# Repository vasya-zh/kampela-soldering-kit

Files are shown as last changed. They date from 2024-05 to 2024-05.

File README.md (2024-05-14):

# kampela-soldering-kit

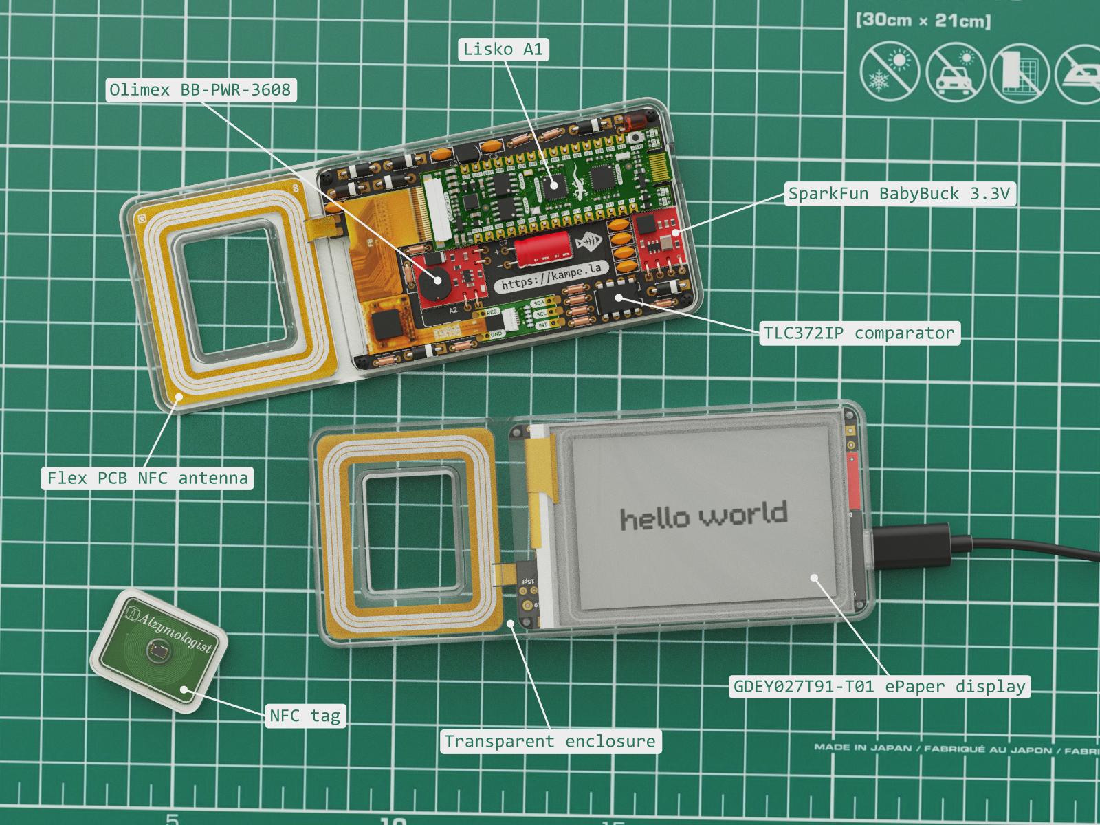
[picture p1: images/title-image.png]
kampela-soldering-kit title image


## Overview

Do-it-yourself kit to make your own, fully-functional Kampela signer

## Features
- Easy to solder and self-assembly transaction signer kit
- NFC-powered batteryless operation
- secure vault implemented in EFM32PG23 MCU
- 2.7" ePaper display with touchscreen
- you can fill the assembled kit with transparent UV-cured glue after assembly and tests to make it unchangeable

## Why did we create this?

We want to make kampela design as transparent, verifiable and open-source as possible, that's simple.

## Components

Kampela solder kit consists of several off-the-shelf modules, simple electronic components and 3d printed parts:

**Modules:**
- 1pc - [Lisko A1](https://github.com/vasya-zh/Lisko) EFM32 devboard
- 1pc - [SparkFun BabyBuck 3.3V](https://www.sparkfun.com/products/18357) - step-down converter module 
- 1pc - [Olimex BB-PWR-3608](https://www.olimex.com/Products/Breadboarding/BB-PWR-3608/open-source-hardware) - step-up converter module 12V/24V
- 1pc - [Touch-6pin-adapter](https://github.com/vasya-zh/kampela-soldering-kit/tree/v2/kicad/touch-6pin-adapter) - 6-pin 0.5mm pitch FPC cable adapter for i2c touch screens
- 1pc - [NFC tag](https://github.com/vasya-zh/kampela-soldering-kit/tree/v2/kicad/tag) PCB with M24SR02 NFC EEPROM chip onboard

**PCBs:**
- 1pc - [Base-board](kicad/base-board/) - main Kampela soldering kit PCB
- 1pc - [flex nfc antenna](https://github.com/vasya-zh/kampela-soldering-kit/tree/v2/kicad/flex-coil8/production) PCB

**3d printed parts:**
- 1pc - [Solder kit enclosure](3d-models/solder-kit-enclosure.stl), 3d printed with transparent SLA resin
- 1pc - [NFC tag enclosure](3d-models/nfc-tag-enclosure.stl), 3d printed with transparent SLA resin

**Electronic components:**
- 1pc - [GDEY027T91-T01](https://www.good-display.com/product/259.html) ePaper display
- 1pc - [TLC372IP](https://www.ti.com/lit/ds/symlink/tlc372.pdf?ts=1715700121988&ref_url=https%253A%252F%252Fwww.google.com%252F) - comparator in DIP8 package
- 1pc - [L78L24](https://www.st.com/resource/en/datasheet/l78l.pdf) - 24V linear voltage regulator in TO-92 package 
- 6pcs - [1N5819](https://www.vishay.com/docs/88525/1n5817.pdf) schottky diode 40V 1A
- 1pc - [1N4743A](https://www.nexperia.com/products/diodes/zener-diodes/1N4743A.html) 13V 1W Zener diode
- 1pc - [3mm red LED](https://www.mouser.fi/ProductDetail/Vishay-Semiconductors/TLDR4900?qs=Lv5%252BaqTFJEN9M2YxsERGfA%3D%3D) for NFC field presence indication 

**Capacitors:**
- 1pc - [15pF 50V](https://www.lcsc.com/product-detail/Multilayer-Ceramic-Capacitors-MLCC-Leaded_TORCH-CC4-0805-CG-50V-15pF-J_C123158.html) ceramic capacitor
- 2pcs - [100pF 50V](https://www.lcsc.com/product-detail/Multilayer-Ceramic-Capacitors-MLCC-Leaded_Murata-Electronics-RCE5C2A101J0DBH03A_C1622101.html) ceramic capacitor
- 2pcs - [0.1uF 50V](https://www.lcsc.com/product-detail/Multilayer-Ceramic-Capacitors-MLCC-Leaded_KNSCHA-178MU0006_C5632430.html) ceramic capacitor
- 2pcs - [1uF 50V](https://www.lcsc.com/product-detail/Multilayer-Ceramic-Capacitors-MLCC-Leaded_KNSCHA-178MU0010_C5632434.html) ceramic capacitor
- 1pc - [220uF 25V](https://www.lcsc.com/product-detail/Aluminum-Electrolytic-Capacitors-Leaded_CX-Dongguan-Chengxing-Elec-KM227M025E11RR0VH2FP0_C12450.html) aluminium capacitor d6.3mm\*11mm

**Resistors:**
- 4pcs - [10k 0.125w](https://www.lcsc.com/product-detail/Through-Hole-Resistors_VO-MF1-8W-10K-1-ST26_C2903381.html) resistor
- 6pcs - [47k 0.125w](https://www.lcsc.com/product-detail/Through-Hole-Resistors_Futaba-Elec-RNU18F4702A520NH_C274421.html) resistor
- 1pc - [300k 0.125w](https://www.lcsc.com/product-detail/Through-Hole-Resistors_TyoHM-RN-1-8W-300K-F-T-B-A1_C433482.html) resistor

Complete CSV BOM can be found [here](docs/kampela-soldering-kit-BOM.csv)

## Assembly instructions

Assembly instructions can be found here: [/docs/assembly-manual.md](docs/assembly-manual.md)

> [!Note] 
> Don't fill your assembly with transparent UV adhesive before you fully test it and flash it with the right firmware.  

## Flashing and testing

Flashing and testing instructions can be found here: [/docs/flashing-n-testing.md](docs/flashing-n-testing.md)

## Using your Kampela Solder Kit

You can use your solder kit as a transaction signer with the real [Kampela firmware](https://github.com/Kalapaja/kampela-firmware)

To do that you need to flash it with the latest [binary firmware released](https://github.com/Kalapaja/kampela-firmware/tags) or build it from the [source code](https://github.com/Kalapaja/kampela-firmware)

Or you can make your customized version of the firmware and hardware.

## How to produce your own Kampela Solder Kit

You can get the kit in [kampe.la](https://kampe.la) shop

Or make your kit. To do that you need:
- order PCBs from your favourite PCB manufacturer. Gerber files can be found here: [base-board](https://github.com/vasya-zh/kampela-soldering-kit/tree/v2/kicad/base-board/production), [flex-antenna](https://github.com/vasya-zh/kampela-soldering-kit/tree/v2/kicad/flex-coil8/production)
- order modules and electronic components, see the [full BOM](docs/kampela-soldering-kit-BOM.csv)
- order or print enclosures with transparent SLA resin. STL and STEP files can be found [here](3d-models/)
- if you want you can also make your version of [Lisko A1](https://github.com/vasya-zh/Lisko) board and [FPC adapter](https://github.com/vasya-zh/kampela-soldering-kit/tree/v2/kicad/touch-6pin-adapter) board. Overwise contact [kampela team](https://kampe.la)

## About this design

Schematic PDF diagrams can be found [here](docs/)

KiCad projects can be found [here](kicad/)

This kit was made using only open-source tools:
- [KiCad](https://www.kicad.org/) - for schematics and PCBs
- [FreeCad](https://www.freecad.org/) - for enclosure design
- [Blender](https://www.blender.org/) - for renders and images
- [InkScape](https://inkscape.org/) - for instructions diagrams

## TODO
- ! Change ePaper and touch screen RESET signal polarity in test and release firmware! 

## Contributors

- [Vasilii Zhuravskii](https://github.com/vasya-zh) - solder kit v2 design, schematics, boards design, DFM, docs, tests

- [Yuri Ilin](https://www.youtube.com/@katsuk) - solder kit v1 design, schematics, flasher firmware, EFM32 test firmware in C with E-INK and other features

This project was made at [Alzymologist Oy](https://github.com/alzymologist) as a part of [Kampela](https://kampe.la) project.

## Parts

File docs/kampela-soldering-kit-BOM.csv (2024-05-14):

Reference | Part Number | URL | Qty | LCSC Part #
A1 | Lisko A1 | https://github.com/vasya-zh/Lisko | 1 | -
A2 | BB-PWR-3608 | https://www.olimex.com/Products/Breadboarding/BB-PWR-3608/open-source-hardware | 1 | -
A3 | BabyBuck 3.3V | https://www.sparkfun.com/products/18357 | 1 | -
A4 | Touch-6pin-adapter | https://github.com/vasya-zh/kampela-soldering-kit/tree/v2/kicad/touch-6pin-adapter | 1 | -
 | NFC tag | https://github.com/vasya-zh/kampela-soldering-kit/tree/v2/kicad/tag | 1 | -
 | Base-board PCB | https://github.com/vasya-zh/kampela-soldering-kit/tree/v2/kicad/base-board | 1 | -
 | Flex NFC antenna PCB | https://github.com/vasya-zh/kampela-soldering-kit/tree/v2/kicad/flex-coil8 | 1 | -
 | Solder kit enclosure | https://github.com/vasya-zh/kampela-soldering-kit/blob/v2/3d-models/solder-kit-enclosure.stl | 1 | -
 | NFC tag enclosure | https://github.com/vasya-zh/kampela-soldering-kit/blob/v2/3d-models/nfc-tag-enclosure.stl | 1 | -
 | GDEY027T91-T01 | https://www.good-display.com/product/259.html | 1 | -
 | M2x3 self-tapping screws |  | 4 | -
 | 1mm thick 10mm double side tape, 2x50mm pieces |  | 2 | -
 | UV transparent adhesive 30ml and UV curing LED |  | 1 | -
C1 | 15pF 100V | https://www.lcsc.com/product-detail/Multilayer-Ceramic-Capacitors-MLCC-Leaded_TORCH-CC4-0805-CG-50V-15pF-J_C123158.html | 1 | C123158
C2,C3 | 1uF 50V | https://www.lcsc.com/product-detail/Multilayer-Ceramic-Capacitors-MLCC-Leaded_KNSCHA-178MU0010_C5632434.html | 2 | C5632434
C4,C5 | 100pF 100V | https://www.lcsc.com/product-detail/Multilayer-Ceramic-Capacitors-MLCC-Leaded_Murata-Electronics-RCE5C2A101J0DBH03A_C1622101.html | 2 | C1622101
C6,C8 | 0,1uF 50V | https://www.lcsc.com/product-detail/Multilayer-Ceramic-Capacitors-MLCC-Leaded_KNSCHA-178MU0006_C5632430.html | 2 | C5632430
C7 | 220uF 25V | https://www.lcsc.com/product-detail/Aluminum-Electrolytic-Capacitors-Leaded_CX-Dongguan-Chengxing-Elec-KM227M025E11RR0VH2FP0_C12450.html | 1 | C12450
D1,D2,D3,D4,D5,D8 | 1N5819 | https://www.vishay.com/docs/88525/1n5817.pdf | 6 | C2474
D6 | XL-234SURD-L | https://www.lcsc.com/product-detail/Light-Emitting-Diodes-LED_XINGLIGHT-XL-234SURD-L_C5440555.html | 1 | C5440555
D7 | 1N4743A | https://www.nexperia.com/products/diodes/zener-diodes/1N4743A.html | 1 | C2546
R1,R7,R8,R9 | 10k | https://www.lcsc.com/product-detail/Through-Hole-Resistors_VO-MF1-8W-10K-1-ST26_C2903381.html | 4 | C2903381
R2,R3,R4,R5,R6,R11 | 47k | https://www.lcsc.com/product-detail/Through-Hole-Resistors_Futaba-Elec-RNU18F4702A520NH_C274421.html | 6 | C274421
R10 | 300k | https://www.lcsc.com/product-detail/Through-Hole-Resistors_TyoHM-RN-1-8W-300K-F-T-B-A1_C433482.html | 1 | C433482
U1 | L7824 | http://www.st.com/content/ccc/resource/technical/document/datasheet/41/4f/b3/b0/12/d4/47/88/CD00000444.pdf/files/CD00000444.pdf/jcr:content/translations/en.CD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 | 1 | C903167
U2 | TLC372IP | https://www.ti.com/lit/ds/symlink/tlc372.pdf?ts=1714659513681 | 1 | C2862094

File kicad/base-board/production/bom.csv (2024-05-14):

Designator | Footprint | Quantity | Value | LCSC Part #
A1 | Lisko_A01-DIP-only | 1 | Lisko_A01 | -
A2 | BB-PWR-3608-in-board | 1 | BB-PWR-3608 | -
A3 | SparkFun_BabyBuck_3.3V-in-board | 1 | BabyBuck 3.3V | -
A4 | touch-6pin-adapter | 1 |  | -
C1 | C_Disc_D5.0mm_W2.5mm_P2.50mm | 1 | 15pF 100V | C123158
C2, C3 | C_Disc_D5.0mm_W2.5mm_P2.50mm | 2 | 1uF 50V | C5632434
C4, C5 | C_Disc_D5.0mm_W2.5mm_P2.50mm | 2 | 100pF 100V | C1622101
C6, C8 | C_Disc_D5.0mm_W2.5mm_P2.50mm | 2 | 0,1uF 50V | C5632430
C7 | CAP_RADIAL_6.3_2.5_11_HOR-DIP | 1 | 220uF 25V | C12450
D1, D2, D3, D4, D5, D8 | D_DO-41_SOD81_P7.62mm_Horizontal | 6 | 1N5819 | C2474
D6 | LED_Rectangular_W3.0mm_H2.0mm | 1 | XL-234SURD-L | C5440555
D7 | D_DO-41_SOD81_P7.62mm_Horizontal | 1 | 13V Zener | C2546
J1, J2 | Pad_1.8x3 | 2 | E_ANT | -
R1, R7, R8, R9 | R_Axial_DIN0204_L3.6mm_D1.6mm_P5.08mm_Horizontal | 4 | 10k | C2903381
R10 | R_Axial_DIN0204_L3.6mm_D1.6mm_P5.08mm_Horizontal | 1 | 300k | C433482
R11, R2, R3, R4, R5, R6 | R_Axial_DIN0204_L3.6mm_D1.6mm_P5.08mm_Horizontal | 6 | 47k | C274421
U1 | TO-92_Inline | 1 | L7824 | C903167
U2 | DIP-8_W7.62mm | 1 | TLC372IP | C2862094

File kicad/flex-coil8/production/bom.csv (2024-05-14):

Designator | Footprint | Quantity | Value | LCSC Part #
_2, |  | 2

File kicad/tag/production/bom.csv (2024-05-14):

Designator | Footprint | Quantity | Value | LCSC Part #
U1 | DFN-8-1EP_3x2mm_P0.5mm_EP1.3x1.5mm | 1 | M24SR02-YMC6T/2

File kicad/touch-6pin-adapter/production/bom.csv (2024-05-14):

Designator | Footprint | Quantity | Value | LCSC Part #
C1 | 0402 | 1 | 0.1uF | C5142567
J1 | HRS_FH34SRJ-6S-0.5SH_50_ | 1 | Conn_01x06 | C5213748
J2, J3 | Connector_Castelled_3pin_2.54mm_withVIA | 2 | Conn_01x03
R1, R2, R3, R4 | 0402 | 4 | 10k | C2906885

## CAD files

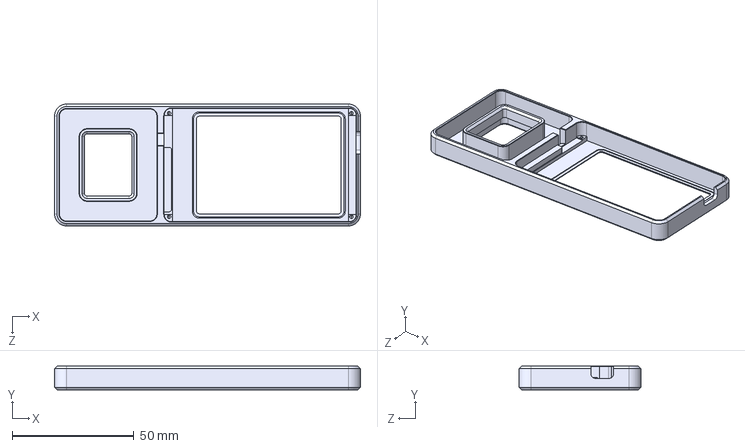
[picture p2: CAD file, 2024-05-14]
3d-models/solder-kit-enclosure.step
125.5 x 9.65 x 50.0 mm

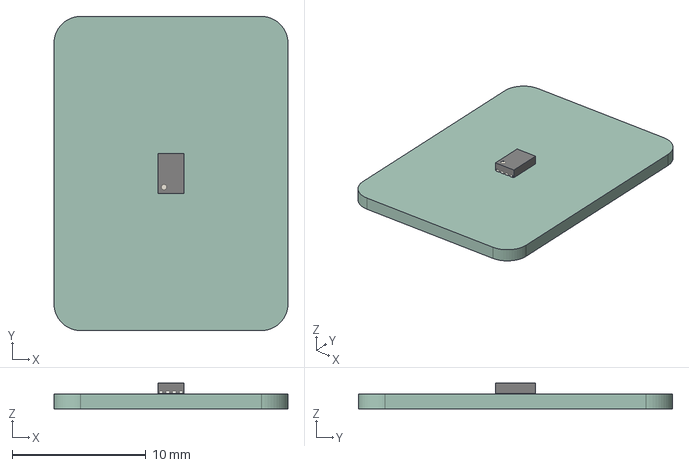
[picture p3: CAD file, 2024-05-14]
kicad/tag/Tag.kicad_G_pcb.step
17.5 x 23.5 x 1.91 mm
DFN-8-1EP_3x2mm_Pitch0.5mm
_autosave-Tag.kicad_G_pcb_PCB

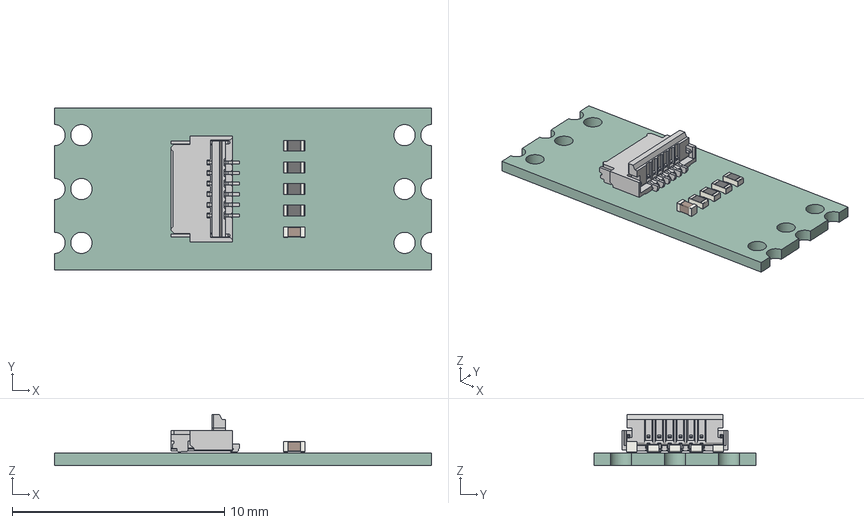
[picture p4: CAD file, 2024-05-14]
kicad/touch-6pin-adapter/touch-6pin-adapter.step
17.8 x 7.62 x 2.42 mm
FH34SRJ-6S_ACTUATOROPEN.PRT
C_0402_1005Metric
R_0402_1005Metric x 4
touch-6pin-adapter_PCB

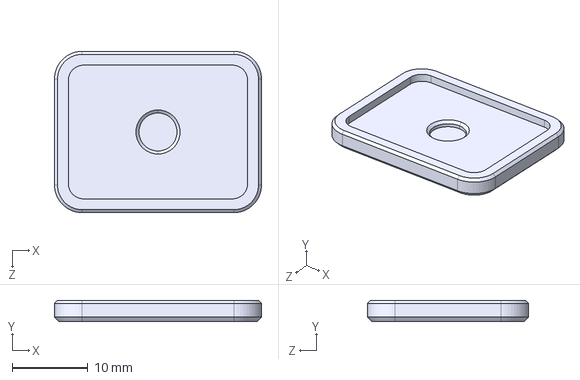
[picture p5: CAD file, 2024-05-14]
3d-models/nfc-tag-enclosure.step
27.2 x 2.80 x 21.2 mm

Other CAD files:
3d-models/nfc-tag-enclosure.stl
3d-models/solder-kit-enclosure.stl

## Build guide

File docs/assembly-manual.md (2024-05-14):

## Assembly Manual

> [!WARNING]
> Use the safety glass and fume extractor (simple 80mm PC vent suits too) to prevent cancer and eye diseases.<br>
> The sun is bright, the water is wet, a soldering iron is hot - be careful!

## Base-board assembly

> [!NOTE]
> A printable version of the base-board Assembly Manual can be found [here](images/base-board-assembly-manual.svg).<br>

0. Tools and materials:
- a soldering iron, 
- a soldering wire, 
- a lot of flux, 
- any cleaning solvent to clean flux after assembly (isopropanol etc) 
- and a good side cutters. 

1. Place and solder the FPC adapter board on the base-board with 6 soldering points:

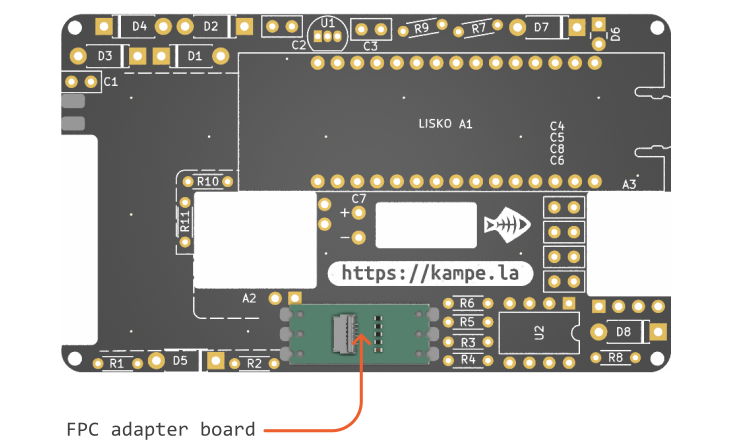
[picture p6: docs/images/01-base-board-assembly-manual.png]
Base-board assembly manual 01


2. Place and solder BB-PWR-3608 and BabyBuck 3.3V - red modules with short insulated or non-insulated copper wires:
	
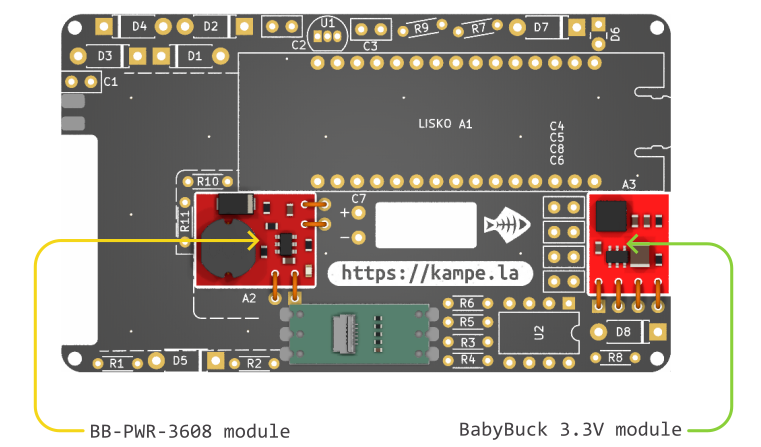
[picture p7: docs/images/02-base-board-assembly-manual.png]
Base-board assembly manual 02


3. Solder all the resistors 10k, 47k and 300k in their places

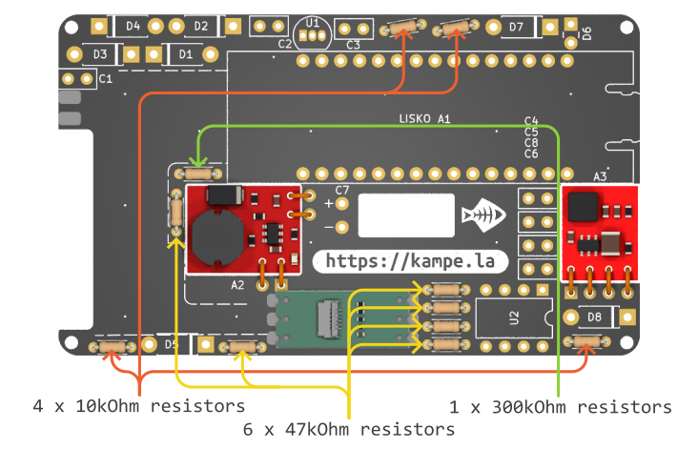
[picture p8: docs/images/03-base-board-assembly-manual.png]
Base-board assembly manual 03


4. Solder all the diodes including 13V Zener (1N4743A) and Schottky (1N5819) diodes

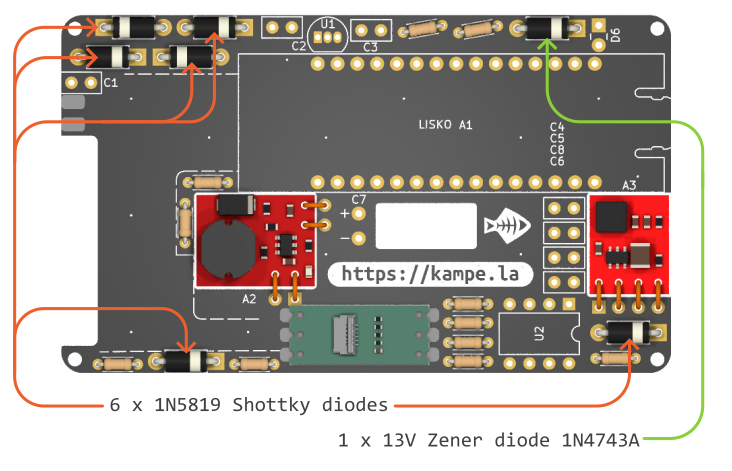
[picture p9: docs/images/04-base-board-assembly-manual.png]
Base-board assembly manual 04


5. Bend to 90 degrees (as short as possible) and solder 3mm red LED (or use the colour you want) to the base-board. Check the polarity on the bottom side of the board.

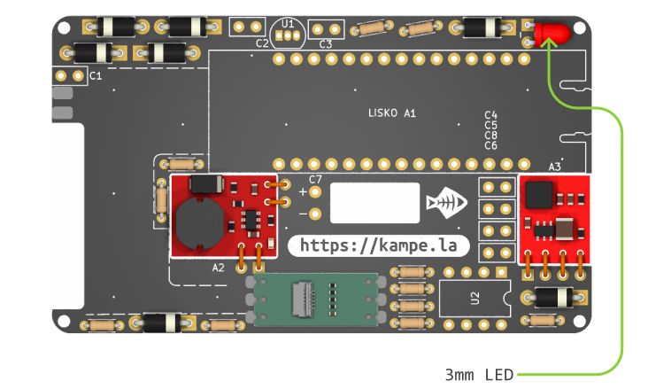
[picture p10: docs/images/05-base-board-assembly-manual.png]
Base-board assembly manual 05


6. Place and solder comparator IC (TLC372IP) and 24V linear regulator (L7824) as close to the board as possible (it will help you to make a flat assembled device).

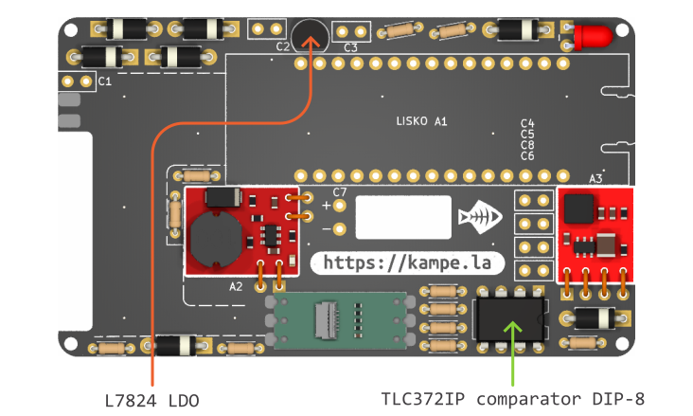
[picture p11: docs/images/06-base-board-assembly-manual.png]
Base-board assembly manual 06


7. Place and solder all capacitors - ceramic disc 15pF, 100pF, 100nF, 1uF (50V or higher voltage) and then aluminium 220uF (not less then 25V)

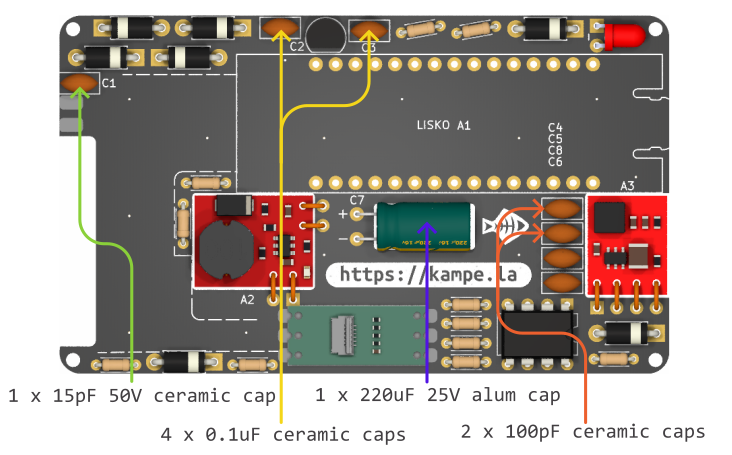
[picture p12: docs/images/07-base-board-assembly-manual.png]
Base-board assembly manual 07


8. Place and solder a Lisko A1 board to the base board using two 15-pin PLS 2.54-pitch male connectors.

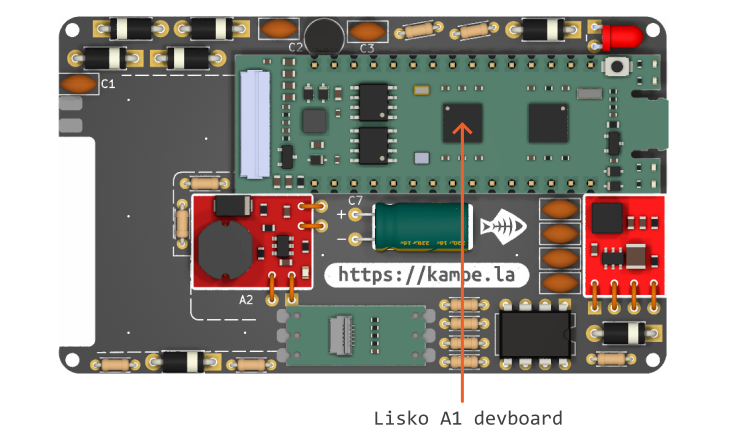
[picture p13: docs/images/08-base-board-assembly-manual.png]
Base-board assembly manual 08


9. Perfect! Now let's cut all the wires on the back side of the base board not higher than 0.5mm and clean the board from flux remains with isopropanol or other solvent

Base-board assembly manual 09

2. Solder the flex coil to the base board with 2 soldering points as shown below. Use water-cleanable or non-clean flux, we don't want to damage the flex coil sticker layer with solvent.

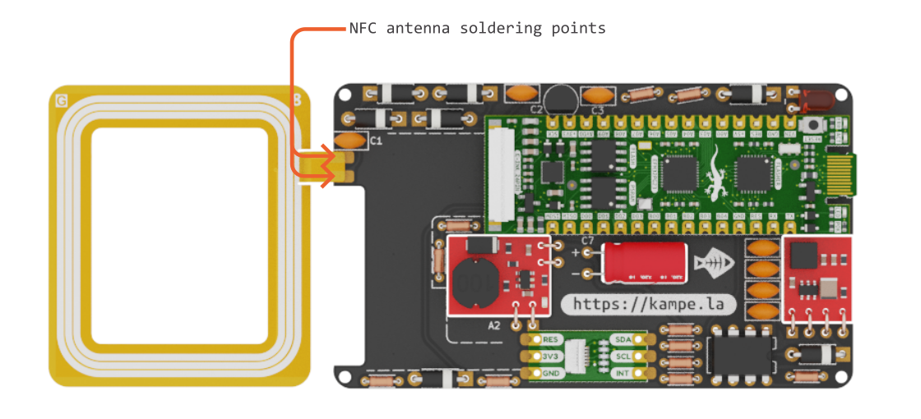
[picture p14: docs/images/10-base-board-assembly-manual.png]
Base-board assembly manual 10


3. Stick the flex dumper to the back side of the 2.7" E-INK display to protect it from PCB back wires and to push it in place 

3. Place the 2.7" E-INK display with a touch screen in the enclosure and push it to the upper edge of its place to align the visible area with the enclosure window. No need to fix it at this stage, it will be secured in place with a flex dumper after fixing the base-board PCB.

4. Install assembled base-board to the enclosure, getting E-INK and Touch screen flex cables outside. Fix it to the enclosure with four M1.6x3 self-tapping screws.

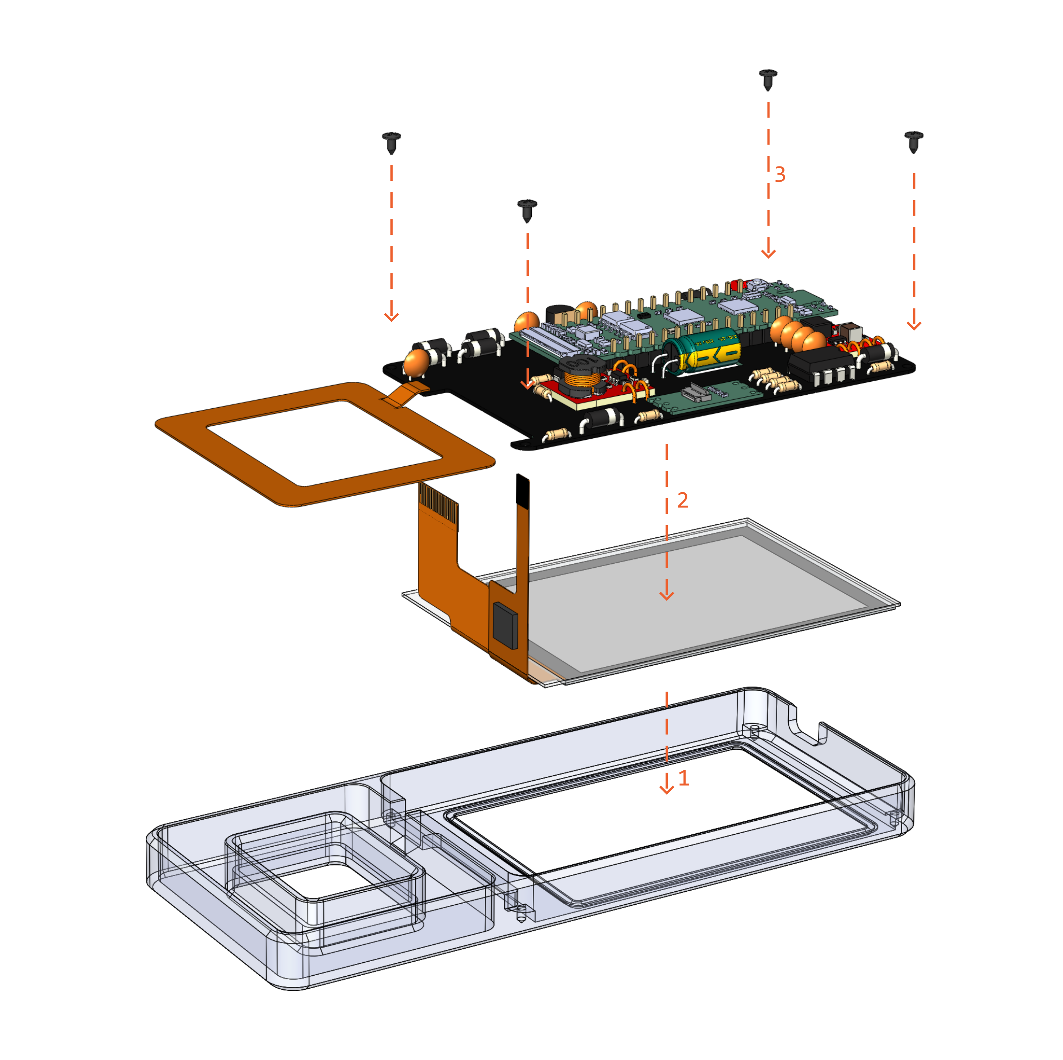
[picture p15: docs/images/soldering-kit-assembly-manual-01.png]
soldering kit assembly manual 01


5. Bend and insert the E-INK and Touch screen flex cables (orange ones) into their connectors - E-INK cable goes to Lisko 24-pin connector, touch screen cable goes to the fpc adapter 6-pin connector.

6. Unstick a protective layer on a flex coil and stick the coil in its place inside the enclosure.

7. Now let's assemble a dummy NFC tag used to initiate NFC communication with a phone. 

	You can use any NFC ISO/IEC 14443 Type A compatible tag you want - it will work with Siltti SDK.

	Or use [kit's NFC tag](https://github.com/Kalapaja/kampela-hardware/tree/main/tag) based on [M24SR02-YMC6T/2](https://www.st.com/en/nfc/m24sr02-y.html) 2-Kbit EEPROM NFC memory

	Install the tag PCB inside a 3d printed enclosure. You can stick it and fill it with transparent UV adhesive if you want but don't forget to test the tag before, for example with NFC Tools. It should be findable and possible to read its uID, that's enough for our task.

	You can use the tag on a key chain with a peace of strong wire. Without it Kampela won't work.

8. Install a companion tag to Kampela enclosure.

7. You've done it! Let's get some Club-Mate, it was a long day!

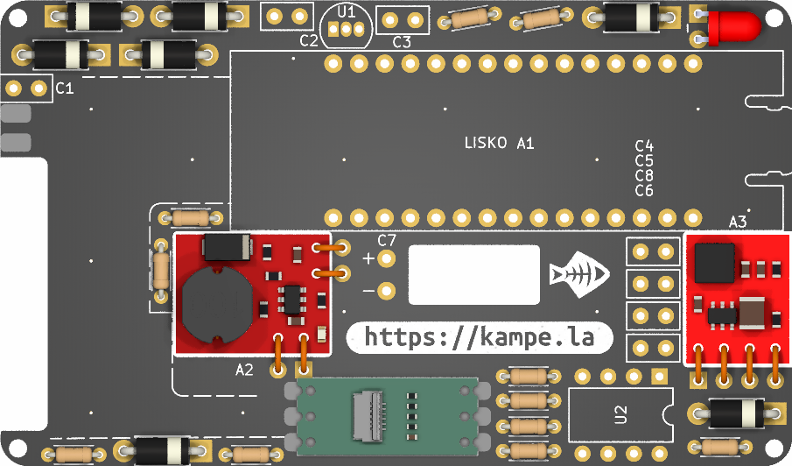
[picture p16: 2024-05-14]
kicad/base-board/images/05_base-board-LED-installed.png

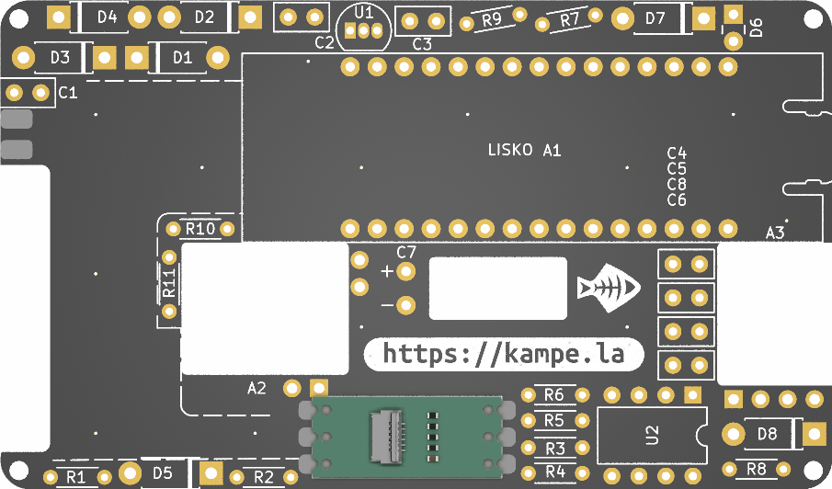
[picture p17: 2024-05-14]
kicad/base-board/images/01_base-board-fpc-adapter-installed.png

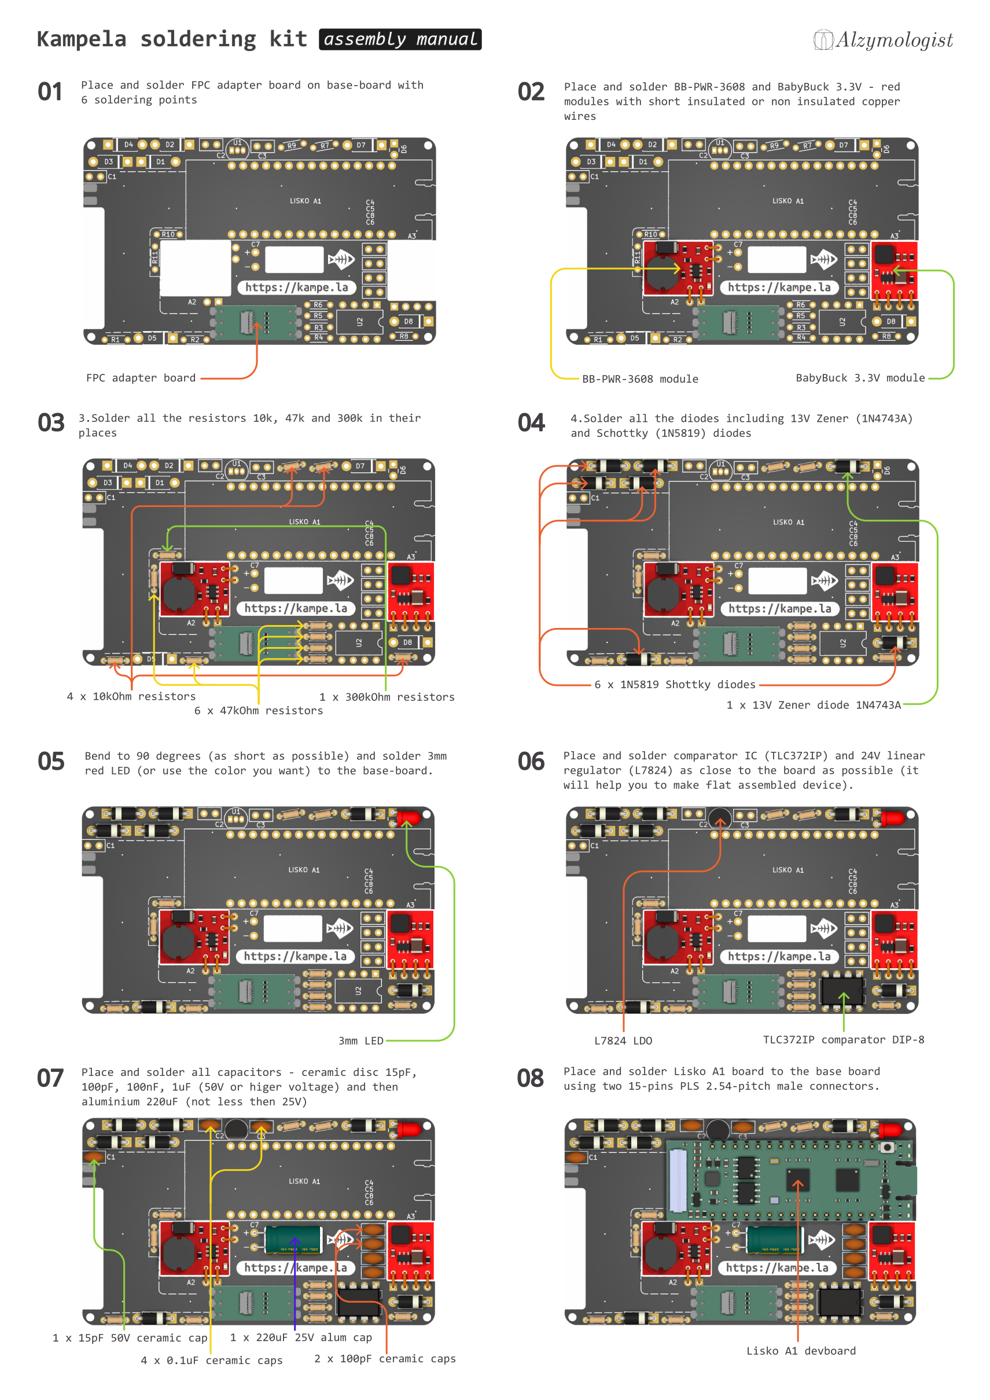
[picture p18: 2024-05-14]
docs/images/base-board-assembly-manual.png

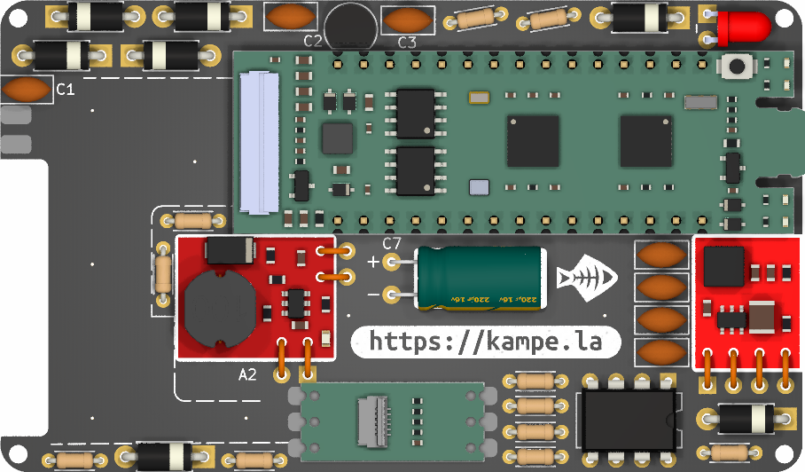
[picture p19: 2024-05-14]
kicad/base-board/images/08_base-board-lisko-installed.png

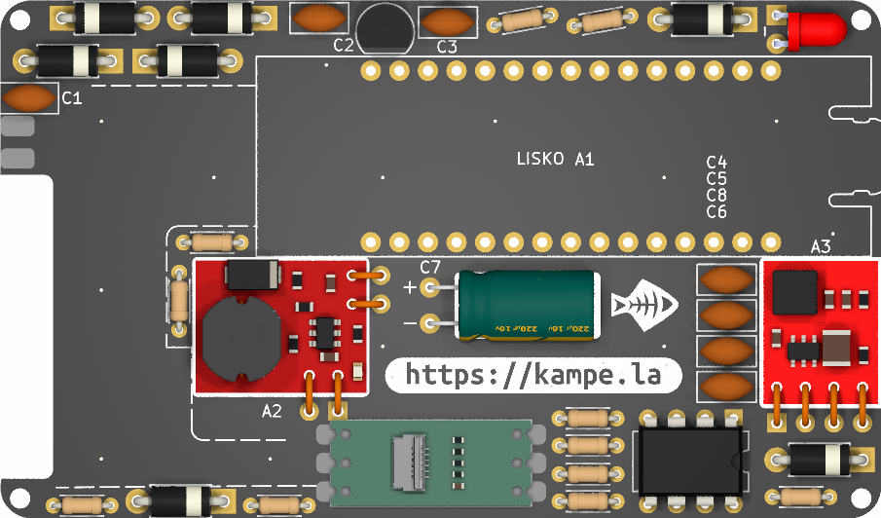
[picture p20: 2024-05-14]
kicad/base-board/images/07_base-board-caps-installed.png

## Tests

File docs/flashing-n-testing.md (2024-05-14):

# Testing and flashing instructions

After assembling your soldering kit you need to test the hardware. To do that you need to go through a simple checklist

1. Visual inspection - check that all components soldered well without unnecessary connections or short circuits with soldering drops. Check that all the boards are clean from flux remains and other contamination.

2. Flash your Lisko flasher MCU (STM32) - instructions are [here](#How-to-flash-your-Lisko-board)

3. After that flash [kampela-solder-kit test firmware binary](../test-firmware/kampela-soldering-kit-test-firmware.bin) using [Pilkki software](https://github.com/Kalapaja/pilkki/tree/main/software) 

4. You can test everything except NFC power/data by simply reconnecting the USB cable. You should see several hardware tests on the screen with OK or ERROR results.

5. To test NFC power/data:

	- Disconnect USB cable
	- Turn on NFC on your smartphone
	- Put NFC-tag inside your assembled Kampela-soldering kit
	- Place Kampela with an NFC tag close to your smartphone's NFC antenna positions. You can find it by googling in images or experimenting with an NFC tag
	- If NFC power is present - the RED LED on Kampela should light bright. Keep this position.
	- In a couple of seconds the test firmware will start performing hardware tests showing results with OK or ERROR messages near each test

6. Now you can flash your Kampela with the latest kampela firmware release from here using [Pilkki software](https://github.com/Kalapaja/pilkki/tree/main/software)

7. You can find instructions for using your Kampela in [kampela-firmware repo](https://github.com/Kalapaja/kampela-firmware)

	Or make your own [kampela-firmware](https://github.com/Kalapaja/kampela-firmware)

## How to flash your Lisko board

First of all, you need to upload the flasher firmware:

0. Install STM32 DFU flashing software for example [stm32cubeprog](https://www.st.com/en/development-tools/stm32cubeprog.html)
	
	Or install alternative DFU software, for example dfu-util tool:
	
	On a Linux machine you can install it using:

	```
	sudo apt-get install dfu-util
	```
	
	for other systems, see http://dfu-util.sourceforge.net/

1. Hold RESET button and connect Lisko to your PC with a USB-C cable

2. STM32 flasher MCU will go to DFU mode and appear in your system as a DFU device. You can check its availability using:

	```
	dfu-util --list
	```
	You should see something like this:
	```
	dfu-util --list
	dfu-util 0.8

	Copyright 2005-2009 Weston Schmidt, Harald Welte and OpenMoko Inc.
	Copyright 2010-2014 Tormod Volden and Stefan Schmidt
	This program is Free Software and has ABSOLUTELY NO WARRANTY
	Please report bugs to dfu-util@lists.gnumonks.org

	Found DFU: [0483:df11] ver=2200, devnum=49, cfg=1, intf=0, alt=3, name="@Device Feature/0xFFFF0000/01*004 e", serial="315A35663432"
	```

3. Now you can flash the flasher by using:

	```
	dfu-util -a 0 --dfuse-address 0x08000000 -D pilkki_0.0.1.bin
	```

	from the folder, there pilkki_0.0.1.bin file was placed. By default, you can find it in [/flasher-firmware](flasher-firmware/) folder of this repository.

4. Perfect!

If you want to tinker with the flasher firmware, you can find the source code in [Pilkki repo](https://github.com/Kalapaja/pilkki/tree/main/firmware)

## How to program your Lisko board

Binary firmware can be uploaded to Lisko EFM32 MCU using [Pilkki software](https://github.com/Kalapaja/pilkki/tree/main/software)

You can find test projects here:

- In C - in [Lisko C test project](https://github.com/vasya-zh/Lisko/tree/A1/test-firmware)

- Or in Rust - [Kampela project](https://github.com/Kalapaja/kampela-firmware)

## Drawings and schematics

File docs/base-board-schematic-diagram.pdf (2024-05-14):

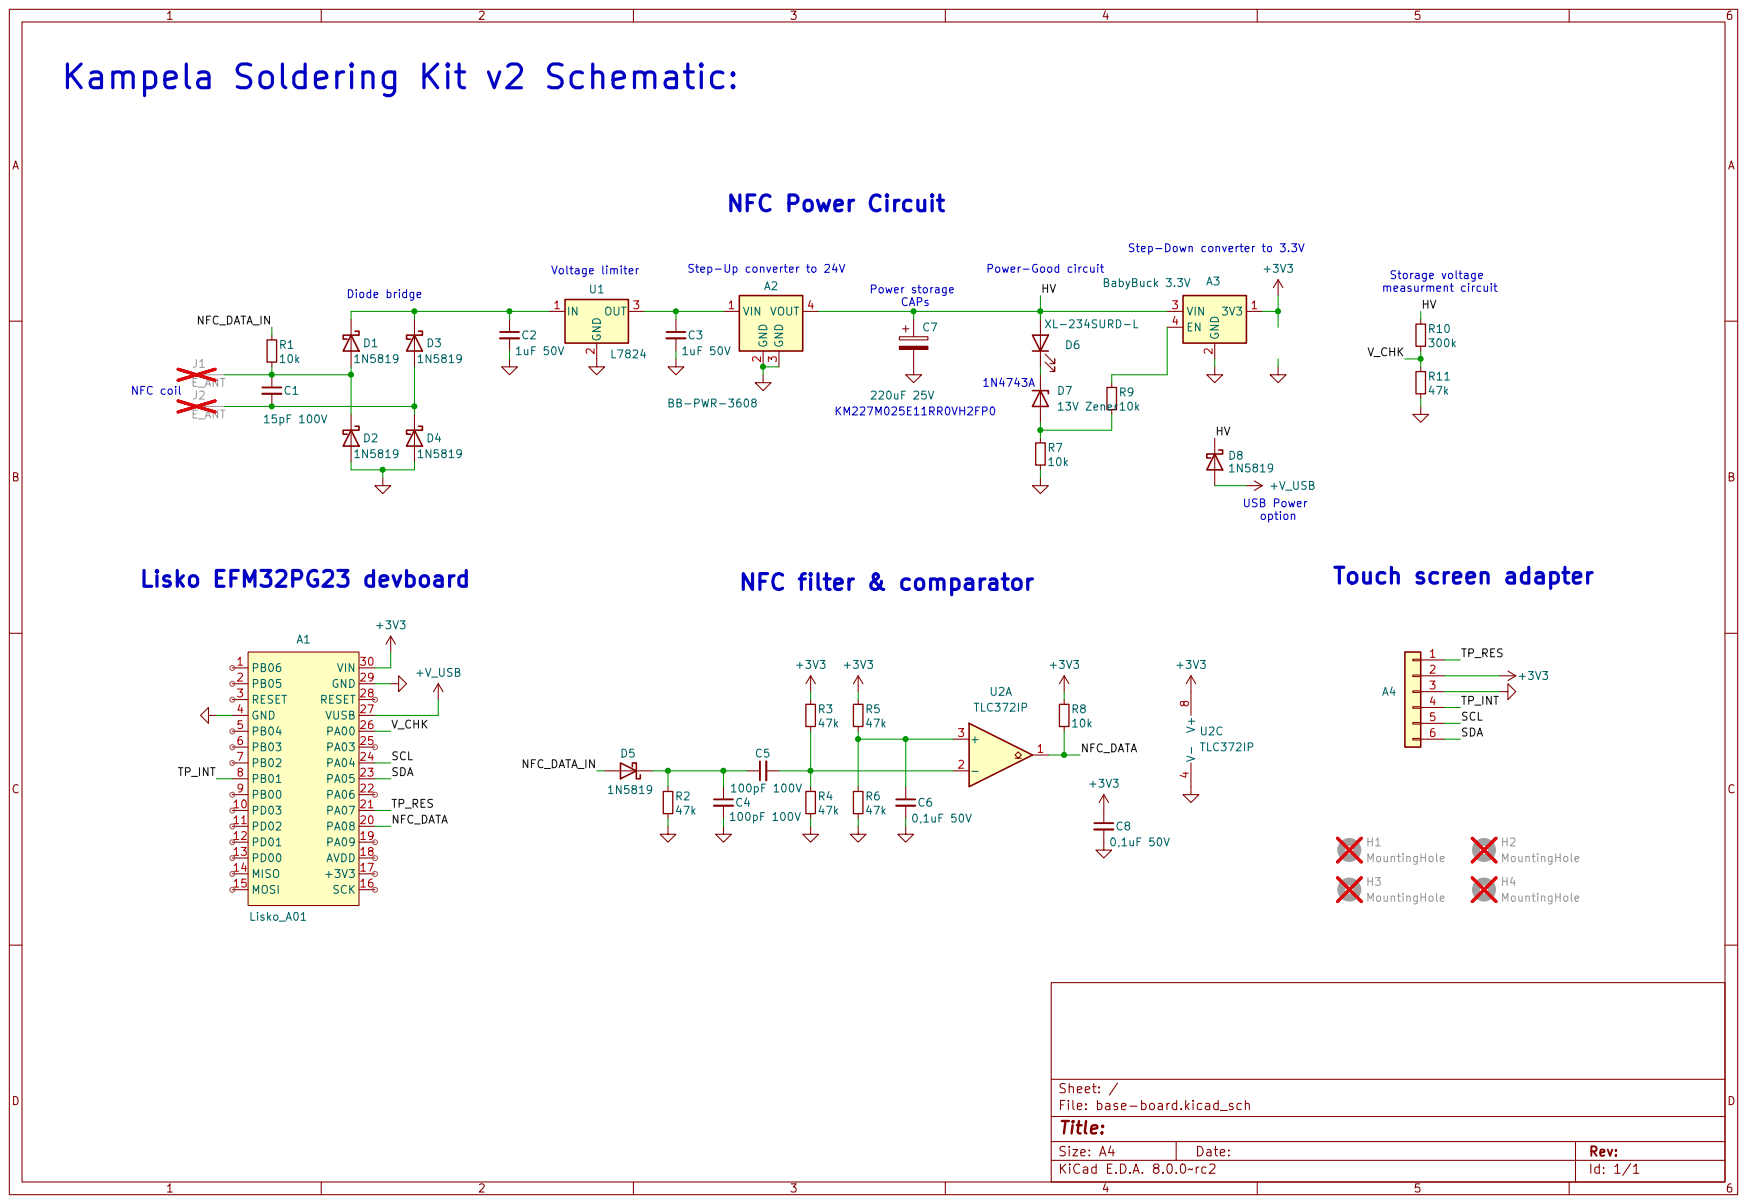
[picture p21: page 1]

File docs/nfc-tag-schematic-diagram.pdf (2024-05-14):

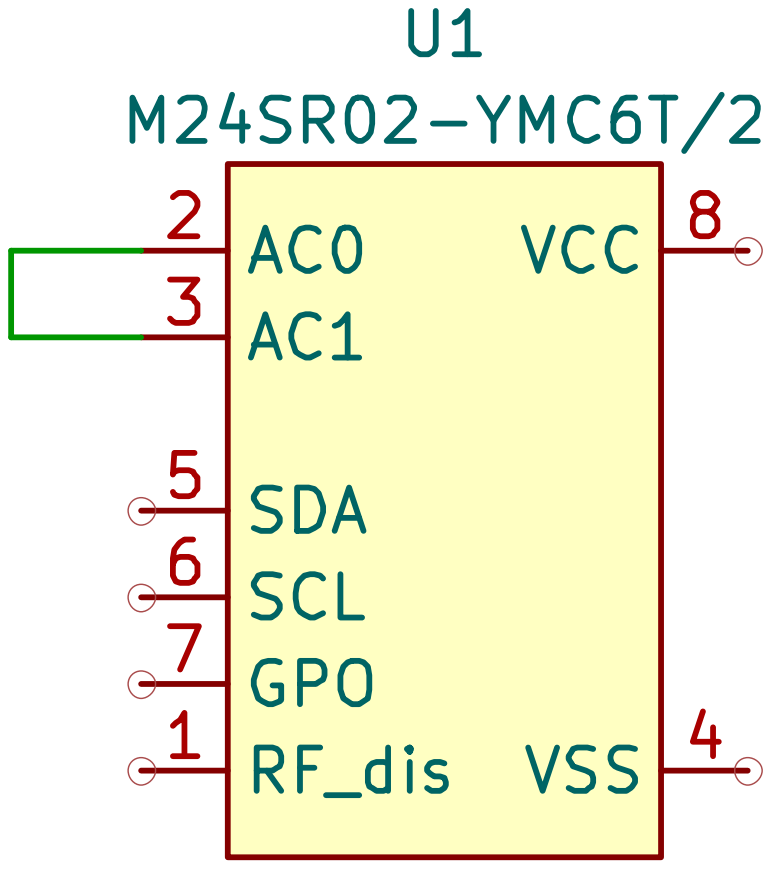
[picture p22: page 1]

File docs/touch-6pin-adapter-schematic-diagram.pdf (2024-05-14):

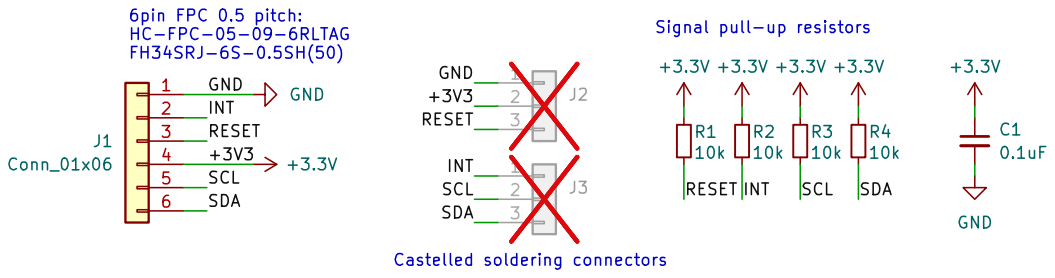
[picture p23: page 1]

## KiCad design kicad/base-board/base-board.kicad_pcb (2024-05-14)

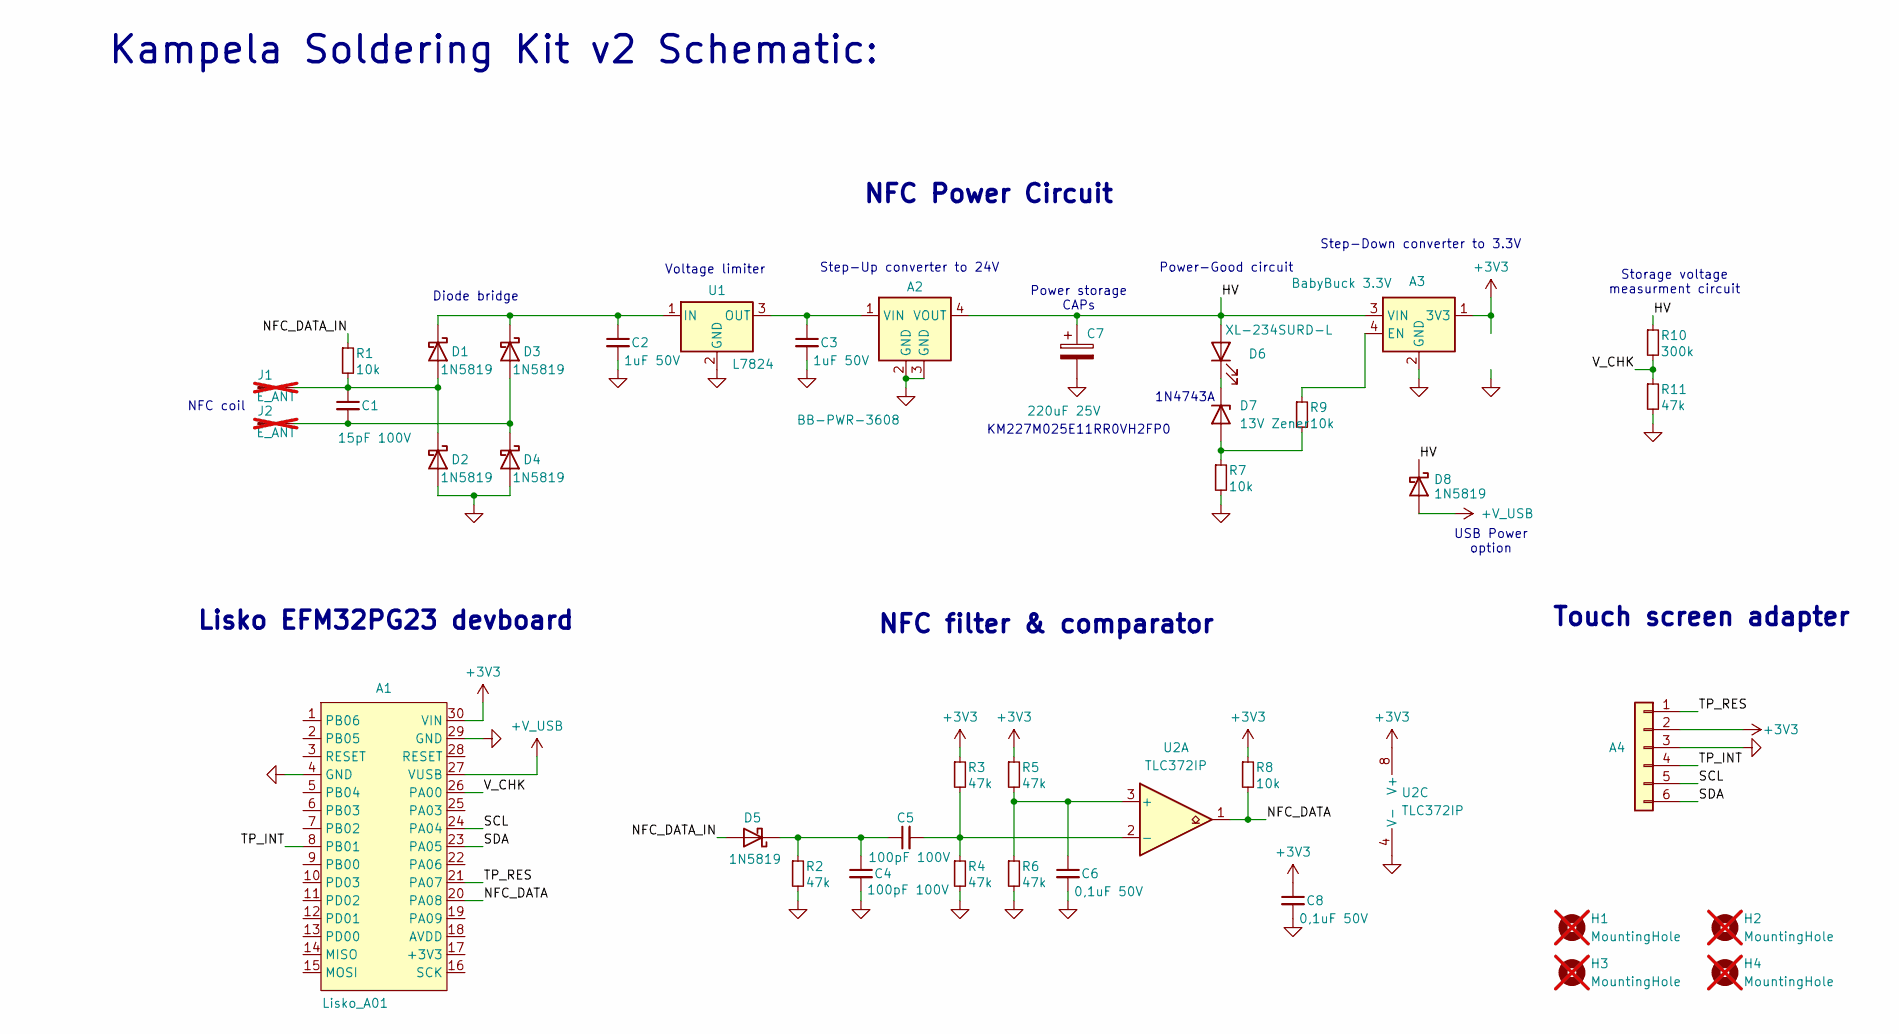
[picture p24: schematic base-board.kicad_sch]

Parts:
A1: Lisko_A01; Lisko_A01-DIP-only
A2: BB-PWR-3608; BB-PWR-3608-in-board
A3: BabyBuck 3.3V; SparkFun_BabyBuck_3.3V-in-board
A4: touch-6pin-adapter
C1: 15pF 100V; C_Disc_D5.0mm_W2.5mm_P2.50mm; Mouser Part # 80-C315C150J1G; LCSC Part # C123158
C2, C3: 1uF 50V; C_Disc_D5.0mm_W2.5mm_P2.50mm; Mouser Part # 81-RCER72A105K2DBH3A; LCSC Part # C5632434
C4, C5: 100pF 100V; C_Disc_D5.0mm_W2.5mm_P2.50mm; Mouser Part # 810-FG18C0G2A101JNT6; LCSC Part # C1622101
C6, C8: 0,1uF 50V; C_Disc_D5.0mm_W2.5mm_P2.50mm; Mouser Part # 80-C320C104K2R5TA; LCSC Part # C5632430
C7: 220uF 25V; CAP_RADIAL_6.3_2.5_11_HOR-DIP; Mouser Part # 710-860010473011; LCSC Part # C12450
D1, D2, D3, D4, D5, D8: 1N5819; D_DO-41_SOD81_P7.62mm_Horizontal; Mouser Part # 637-1N5819; LCSC Part # C2474
D6: XL-234SURD-L; LED_Rectangular_W3.0mm_H2.0mm; Mouser Part # 604-WP424IDT; LCSC Part # C5440555
D7: 13V Zener; D_DO-41_SOD81_P7.62mm_Horizontal; Mouser Part # 771-1N4743A-T/R; LCSC Part # C2546
H1, H2, H3, H4: MountingHole; MountingHole_2.1mm; not fitted
J1, J2: E_ANT; Pad_1.8x3; not fitted
R1, R7, R8, R9: 10k; R_Axial_DIN0204_L3.6mm_D1.6mm_P5.08mm_Horizontal; Mouser Part # 303-MF0W8FF1002A20; LCSC Part # C2903381
R2, R3, R4, R5, R6, R11: 47k; R_Axial_DIN0204_L3.6mm_D1.6mm_P5.08mm_Horizontal; Mouser Part # 303-MF0W8FF4702B00; LCSC Part # C274421
R10: 300k; R_Axial_DIN0204_L3.6mm_D1.6mm_P5.08mm_Horizontal; Mouser Part # 71-RN55E3003B; LCSC Part # C433482
U1: L7824; TO-92_Inline; Mouser Part # 863-MC79L24ACPRMG; LCSC Part # C903167
U2: TLC372IP; DIP-8_W7.62mm; Mouser Part # 595-TLC372IP; LCSC Part # C2862094

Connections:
+3V3: A1.30 (VIN), A3.1 (3V3), A4.2, C8.1, R3.1, R5.1, R8.1, U2.8 (V+)
+V_USB: A1.27 (VUSB), D8.2 (A)
/HV: A2.4 (VOUT), A3.3 (VIN), C7.1, D6.2 (A), D8.1 (K), R10.1
/NFC_DATA: A1.20 (PA08), R8.2, U2.1
/NFC_DATA_IN: D5.2 (A), R1.1
/SCL: A1.24 (PA04), A4.5
/SDA: A1.23 (PA05), A4.6
/TP_INT: A1.8 (PB01), A4.4
/TP_RES: A1.21 (PA07), A4.1
/V_CHK: A1.26 (PA00), R10.2, R11.1
GND: A1.4 (GND), A1.29 (GND), A2.2 (GND), A2.3 (GND), A3.2 (GND), A4.3, C2.2, C3.2, C4.2, C6.2, C7.2, C8.2, D2.2 (A), D4.2 (A), R2.2, R4.2, R6.2, R7.2, R11.2, U1.2 (GND), U2.4 (V-)
unnamed: A2.1 (VIN), C3.1, U1.3 (OUT)
unnamed: A3.4 (EN), R9.1
unnamed: C1.1, D1.2 (A), D2.1 (K), J1.1, R1.2
unnamed: C2.1, D1.1 (K), D3.1 (K), U1.1 (IN)
unnamed: C1.2, D3.2 (A), D4.1 (K), J2.1
unnamed: C4.1, C5.1, D5.1 (K), R2.1
unnamed: D6.1 (K), D7.1 (K)
unnamed: D7.2 (A), R7.1, R9.2
unnamed: C6.1, R5.2, R6.1, U2.3 (+)
unnamed: C5.2, R3.2, R4.1, U2.2 (-)

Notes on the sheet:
1N4743A
Lisko EFM32PG23 devboard
Kampela Soldering Kit v2 Schematic:
NFC Power Circuit
Step-Down converter to 3.3V
KM227M025E11RR0VH2FP0
USB Power option
NFC filter & comparator
Voltage limiter
Storage voltage measurment circuit
Diode bridge
Touch screen adapter
NFC coil
Step-Up converter to 24V
Power-Good circuit
Power storage CAPs

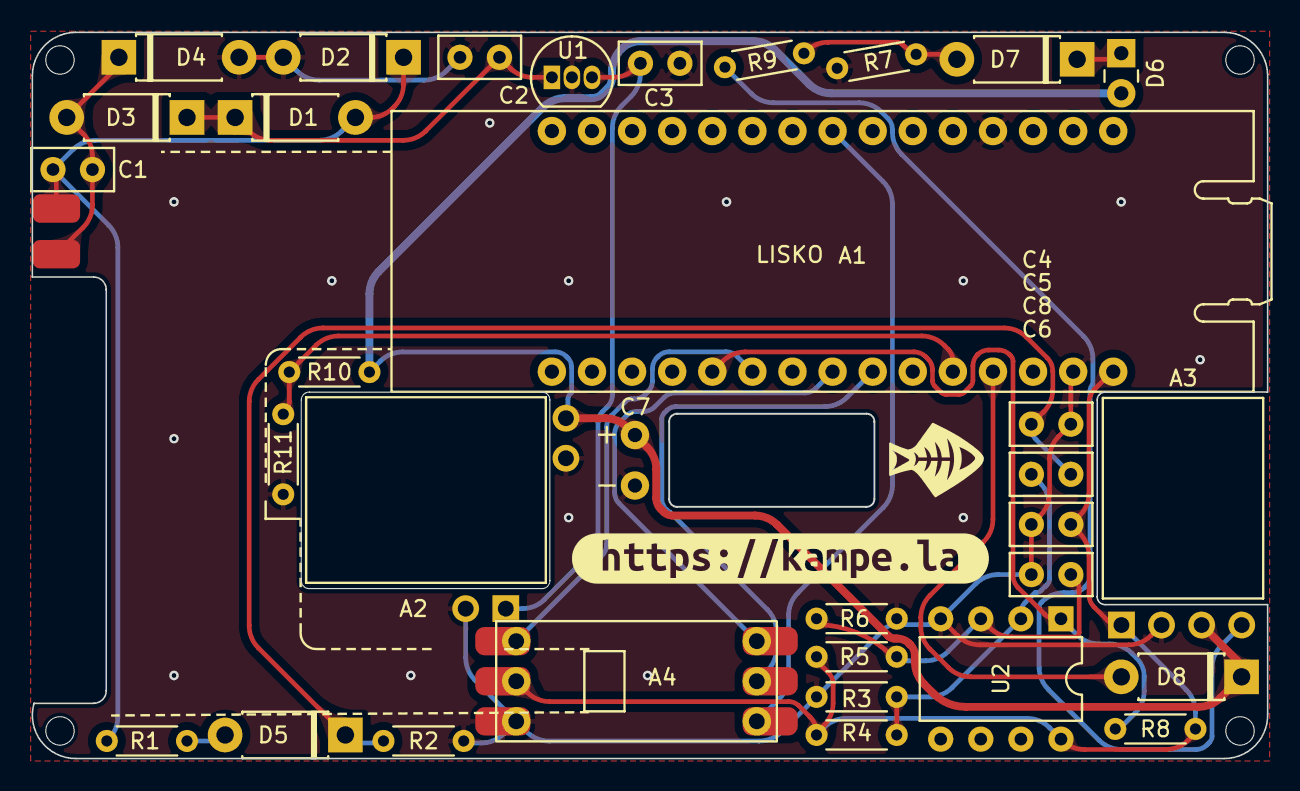
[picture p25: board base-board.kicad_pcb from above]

Board: 2 copper layers, 78.2 x 46.0 mm, 43 parts (0 on the bottom side), 21 nets.

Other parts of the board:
H2#2, H3#2, H4#2: MountingHole; MountingHole_2.1mm
kibuzzard-6635354C: G***; kibuzzard-6635354C

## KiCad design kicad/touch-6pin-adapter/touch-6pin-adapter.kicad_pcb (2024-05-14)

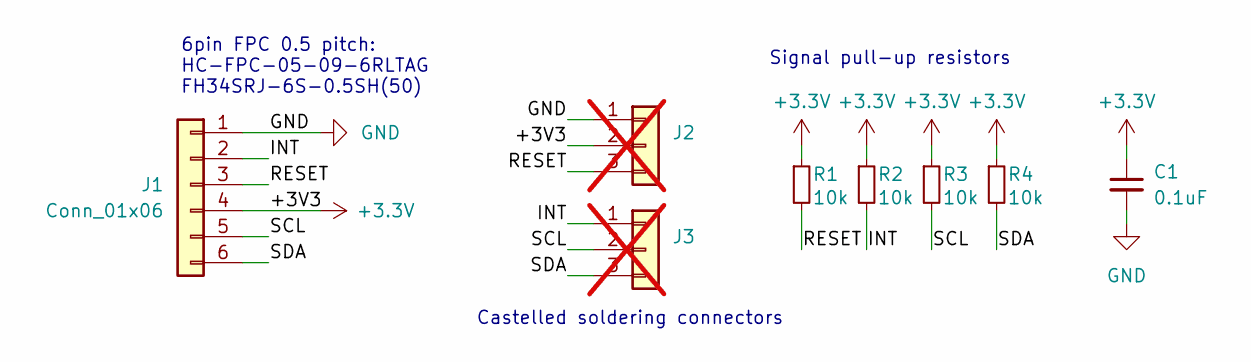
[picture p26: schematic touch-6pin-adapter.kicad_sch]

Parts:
C1: 0.1uF; C_0402_1005Metric; LCSC Part # C5142567
J1: Conn_01x06; HRS_FH34SRJ-6S-0.5SH_50_; LCSC Part # C5213748
J2, J3: Conn_01x03; Connector_Castelled_3pin_2.54mm_withVIA; not fitted
R1, R2, R3, R4: 10k; R_0402_1005Metric; LCSC Part # C2906885

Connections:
+3.3V: C1.1, J1.4, J2.2, R1.1, R2.1, R3.1, R4.1
/INT: J1.2, J3.1, R2.2
/RESET: J1.3, J2.3, R1.2
/SCL: J1.5, J3.2, R3.2
/SDA: J1.6, J3.3, R4.2
GND: C1.2, J1.1, J2.1

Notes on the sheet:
Signal pull-up resistors
6pin FPC 0.5 pitch: HC-FPC-05-09-6RLTAG FH34SRJ-6S-0.5SH(50)
Castelled soldering connectors

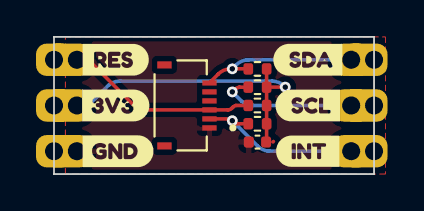
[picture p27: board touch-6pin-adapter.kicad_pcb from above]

Board: 2 copper layers, 17.8 x 7.6 mm, 14 parts (0 on the bottom side), 6 nets.

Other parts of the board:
kibuzzard-663390A2: G***; kibuzzard-663390A2
kibuzzard-663390A9: G***; kibuzzard-663390A9
kibuzzard-663390E6: G***; kibuzzard-663390E6
kibuzzard-6633914E: G***; kibuzzard-6633914E
kibuzzard-66339095: G***; kibuzzard-66339095
kibuzzard-66339126: G***; kibuzzard-66339126
